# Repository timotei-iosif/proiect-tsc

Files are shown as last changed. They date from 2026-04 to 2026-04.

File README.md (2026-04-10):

# InkTime

In acest proiect a trebuit implementata o schema electrica data de catre echipa
de TSC in Fusion

## Diagrama bloc

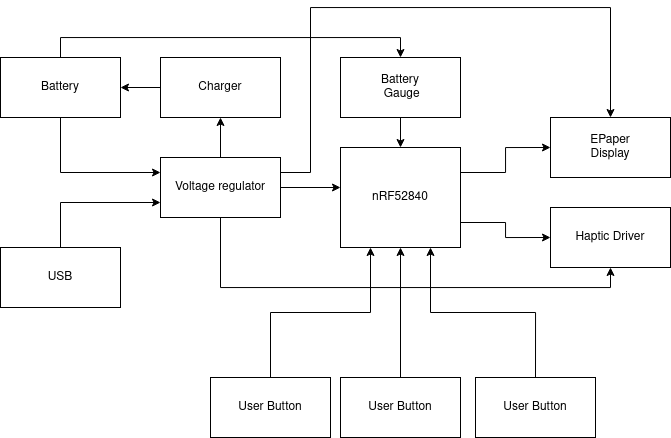
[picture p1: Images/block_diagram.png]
Diagrama block Diagrama bloc


## BOM

|Quantity|Value |Manufacturer Part Number|Link JLCPARTS |
|---|---|---|---|
|1 |2450AT18B100E |2450AT18B100E |https://jlcpcb.com/partdetail/JohansonDielectrics-2450AT18B100E/C2917717 |
|16 |1uF |GRM155R70J105KA12D |https://jlcpcb.com/partdetail/MurataElectronics-GRM155R70J105KA12D/C88945|
|3 |10uF |CC0402MRX7R6BB106 |https://jlcpcb.com/partdetail/YAGEO-CC0402MRX7R6BB106/C3202927 |
|10 |0.1uF |CL03A104KP3NNNC |https://jlcpcb.com/partdetail/50070-CL03A104KP3NNNC/C49062 |
|2 |22uF |CL05A226MQ5QUNC |https://jlcpcb.com/partdetail/YAGEO-CC0402MRX7R6BB106/C3202927 |
|5 |4.7uF |GRM155R61E475ME15D |https://jlcpcb.com/partdetail/3058877-GRM155R61E475ME15D/C2858031 |
|1 |4.7uF/25V |GRM155R61E475ME15D |https://jlcpcb.com/partdetail/3058877-GRM155R61E475ME15D/C2858031 |
|1 |47nF |GRM155R71E473KA88D |https://jlcpcb.com/partdetail/MurataElectronics-GRM155R71E473KA88D/C77017|
|3 |NC | | |
|4 |12pF |GRM0335C1E120JA01D |https://jlcpcb.com/partdetail/172753-GRM0335C1E120JA01D/C161372 |
|1 |100pF |GRM0335C1E101JA01D |https://jlcpcb.com/partdetail/MurataElectronics-GRM0335C1E101JA01D/C76917|
|2 |1pF |GRM0335C1E1R0BA01D |https://jlcpcb.com/partdetail/MurataElectronics-GRM0335C1E1R0BA01D/C88903|
|1 |820pF/NC |GRM0335C1E1R0BA01D |https://jlcpcb.com/partdetail/MurataElectronics-GRM0335C1E1R0BA01D/C88903|
|1 |USBLC6-2SC6Y |USBLC6-2SC6Y |https://jlcpcb.com/partdetail/STMicroelectronics-USBLC62SC6Y/C2969755 |
|3 |MBR0530 |MBR0530 |https://jlcpcb.com/partdetail/78464-MBR0530/C77336 |
|1 |BQ25180YBGR |BQ25180YBGR |https://jlcpcb.com/partdetail/TexasInstruments-BQ25180YBGR/C3682423 |
|1 |RT6160AWSC |RT6160AWSC |https://jlcpcb.com/partdetail/RichtekTech-RT6160AWSC/C7065276 |
|1 |BMA423 |BMA423 |https://jlcpcb.com/partdetail/BoschSensortec-BMA423/C189517 |
|1 |DRV2605YZFR |DRV2605YZFR |https://jlcpcb.com/partdetail/TexasInstruments-DRV2605YZFR/C81079 |
|1 |503480-2400 |503480-2400 |https://jlcpcb.com/partdetail/MOLEX-5034802400/C122434 |
|1 |KH-TYPE-C-16P_KH-TYPE-C-16P |KH-TYPE-C-16P |https://jlcpcb.com/partdetail/Shenzhen_KinghelmElec-KH_TYPE_C16P/C709357 |
|1 |TC2030-IDC |TC2030-IDC |- |
|1 |FTC252012SR47MBCA |FTC252012SR47MBCA |https://jlcpcb.com/partdetail/6763488-FTC252012SR47MBCA/C5832368 |
|1 |68uH |CMI322513J680M |https://jlcpcb.com/partdetail/61593-CMI322513J680M/C60541 |
|1 |10uH |SDFL2012S100KTF |https://jlcpcb.com/partdetail/Sunlord-SDFL2012S100KTF/C1046 |
|1 |15uH |CMI201209J150KT |https://jlcpcb.com/partdetail/76759-CMI201209J150KT/C75634 |
|1 |3.9nH |CMI201209U3R9KT |https://jlcpcb.com/partdetail/70603-CMI201209U3R9KT/C69486 |
|1 |SI1308EDL-T1-GE3 |SI1308EDL-T1-GE3 |https://jlcpcb.com/partdetail/VishayIntertech-SI1308EDL_T1GE3/C469327 |
|1 |20V/4.2A/52mOhm/1.4W |AO3401A |https://jlcpcb.com/partdetail/Alpha_OmegaSemicon-AO3401A/C15127 |
|6 |10k |CR0201FH1002G |https://jlcpcb.com/partdetail/LIZElec-CR0201FH1002G/C100126 |
|3 |0 |RC0201FR-070RL |https://jlcpcb.com/partdetail/YAGEO-RC0201FR070RL/C106227 |
|2 |3k3 |RM02JTN332 |https://jlcpcb.com/partdetail/TA_ITech-RM02JTN332/C162771 |
|2 |5k1 |CR0201FH5101G |https://jlcpcb.com/partdetail/LIZElec-CR0201FH5101G/C100142 |
|1 |0.47 |RL73V1HR47FTDF |https://jlcpcb.com/partdetail/TEConnectivity-RL73V1HR47FTDF/C2139167 |
|1 |2.2 |RTT012R2JTH |https://jlcpcb.com/partdetail/RALEC-RTT012R2JTH/C102714 |
|1 |MAX17048G+T10 |MAX17048G+T10 |https://jlcpcb.com/partdetail/2777647-MAX17048GT10/C2682616 |
|1 |NRF52840_QF |NRF52840_QF |https://jlcpcb.com/partdetail/NordicSemicon-NRF52840_QFAA_FR/C3606918 |
|1 |32Mhz |830108212909 |https://jlcpcb.com/partdetail/357112-X201632MMB4SI/C383840 |
|1 |32.768kHz |X201632MMB4SI |https://jlcpcb.com/partdetail/SeikoEpson-Q13FC13500004/C32346 |

## Module folosite

### 1. Mcu

Controlerul principal al placii este un nRF52840, bazat pe un nucleu ARM
Cortex-M4F la 64 MHz.

* Clocking: Sistemul utilizeaza doua ceasuri. Un oscilator extern de 32 MHz
  pentru core, periferice si RF, si oscilator de 32.768 kHz este utilizat
  pentru RTC
* Interfata RF: 2450AT18B100E - banda de 2.4 GHz, integrata cu o retea de
  adaptare a impedantei formata din componente pasive
* Interfete de date:
    * **I2C:** Magistrala pentru senzor IMU, fuel gauge, charger, driver haptic
    * **SPI:** Pentru display-ul E-Paper.
    * **USB:** Liniile D+ ai D- sunt rutate direct la pinii nativi ai nRF52840

### 2. Module

* **Incarcare:** Implementat cu un BQ25180. Preia tensiunea de 5V de pe
  magistrala VBUS (USB) si gestioneaza ciclul de incarcare al celulei LiPo.
  Configurabil folosind I2C + PMIC\_INT
* **Regulatoare:** Buck-boost - Richtek RT6160. Rolul sau este sa asigure o
  tensiune stabila de 3.3V
* **Monitorizare:** MAX17048 citeste starea de incarcare a bateriei. Ofera
  alerte hardware la praguri predefinite de descarcare.
* **Afisaj E-Paper**
* **Sistem Haptic:** - DRV2605. Este comandat prin I2C si activat via pinul
  HAPTIC\_EN`.
* **Inertial Measurement Unit (IMU):** BMA421. Liniile de intrerupere
  (`IMU\_INT1`, `IMU\_INT2`) sunt folosite pentru algoritmul de wake-on-tilt.
* **3 Butoane fizice**

## 3. Calcule Estimative de Consum (Power Budget)

1.  **Standby**: ~10 - 20 uA
2.  **Radio activ (BLE TX/RX): ~5 - 15 mA**
3.  **Actualizare Display (Refresh E-Paper):** ~5 - 15 mA (timp de 1-3 secunde)
4.  **Feedback Haptic:** 50 - 100+ mA pentru perioade scurte

## Pini de nRF52840

Conform manualului de referinta a nRF52840 pinii pentru protocoale digitale (cu
exceptia USB si SWD) pot fi rutati la orice pin fizic ai microcontrollerului.
Alegerea pinilor pentru aceste protocoale a fost facuta pentru a facilita
rutarea de semnale.

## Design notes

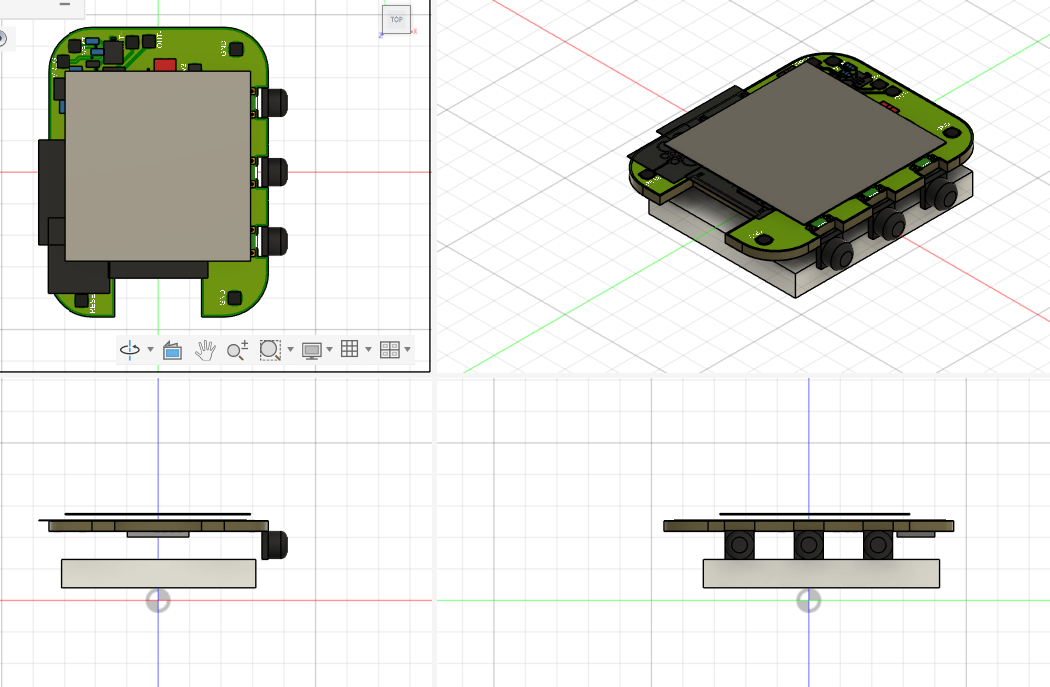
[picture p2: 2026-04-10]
Images/3D.png

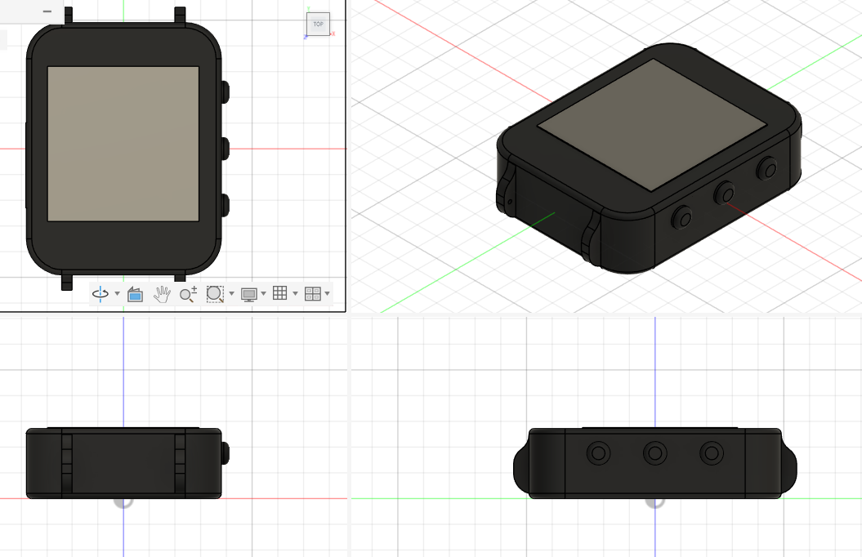
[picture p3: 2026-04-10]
Images/3D_2.png

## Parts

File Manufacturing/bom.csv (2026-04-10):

Reference Designators | Quantity | Description | Package | Value | Manufacturer Part Number | Link JLCPARTS
 | 1 | PCB Board | Board
ANT1 | 1 | Antennas 2.45GHz ANTENNA | 2450AT18B100E_ANTC3216X140N | 2450AT18B100E | 2450AT18B100E | https://jlcpcb.com/partdetail/JohansonDielectrics-2450AT18B100E/C2917717
C1, C3, C11, C14, C15, C16, C19, C20, C22, C23, C24, C25, C26, C27, C28, C31 | 16 | Generic chip capacitor | NORDIC_NRF_3_RESC0402_N | 1uF | GRM155R70J105KA12D | https://jlcpcb.com/partdetail/MurataElectronics-GRM155R70J105KA12D/C88945
C2, C4, C18 | 3 | Generic chip capacitor | NORDIC_NRF_3_RESC0402_N | 10uF | CC0402MRX7R6BB106 | https://jlcpcb.com/partdetail/YAGEO-CC0402MRX7R6BB106/C3202927
C5, C8, C9, C10, C13, C21, C30, C34, C43, C44 | 10 | Generic chip capacitor | NORDIC_NRF_3_RESC0201_N | 0.1uF | CL03A104KP3NNNC | https://jlcpcb.com/partdetail/50070-CL03A104KP3NNNC/C49062
C6, C7 | 2 | Generic chip capacitor | NORDIC_NRF_3_RESC0402_N | 22uF | CL05A226MQ5QUNC | https://jlcpcb.com/partdetail/YAGEO-CC0402MRX7R6BB106/C3202927
C12, C29, C45, C46, C47 | 5 | Generic chip capacitor | NORDIC_NRF_3_RESC0402_N | 4.7uF | GRM155R61E475ME15D | https://jlcpcb.com/partdetail/3058877-GRM155R61E475ME15D/C2858031
C17 | 1 | Generic chip capacitor | NORDIC_NRF_3_RESC0402_N | 4.7uF/25V | GRM155R61E475ME15D | https://jlcpcb.com/partdetail/3058877-GRM155R61E475ME15D/C2858031
C32 | 1 | Generic chip capacitor | NORDIC_NRF_3_RESC0201_N | 47nF | GRM155R71E473KA88D | https://jlcpcb.com/partdetail/MurataElectronics-GRM155R71E473KA88D/C77017
C33, C38, C41 | 3 | Generic chip capacitor | NORDIC_NRF_3_RESC0201_N | NC
C35, C36, C48, C49 | 4 | Generic chip capacitor | NORDIC_NRF_3_RESC0201_N | 12pF | GRM0335C1E120JA01D | https://jlcpcb.com/partdetail/172753-GRM0335C1E120JA01D/C161372
C37 | 1 | Generic chip capacitor | NORDIC_NRF_3_RESC0201_N | 100pF | GRM0335C1E101JA01D | https://jlcpcb.com/partdetail/MurataElectronics-GRM0335C1E101JA01D/C76917
C39, C40 | 2 | Generic chip capacitor | NORDIC_NRF_3_RESC0201_N | 1pF | GRM0335C1E1R0BA01D | https://jlcpcb.com/partdetail/MurataElectronics-GRM0335C1E1R0BA01D/C88903
C42 | 1 | Generic chip capacitor | NORDIC_NRF_3_RESC0201_N | 820pF/NC | GRM0335C1E1R0BA01D | https://jlcpcb.com/partdetail/MurataElectronics-GRM0335C1E1R0BA01D/C88903
D1 | 1 | Low Cap. ESD Protection Auto SOT-23-6 STMicroelectronics USBLC6-2SC6Y, Dual Uni-Directional TVS Diode Array, 6-Pin SOT-23 | ESP32_C6_LIBRARY_3_SOT95P280X145-6N | USBLC6-2SC6Y | USBLC6-2SC6Y | https://jlcpcb.com/partdetail/STMicroelectronics-USBLC62SC6Y/C2969755
D2, D3, D4 | 3 | ON SEMICONDUCTOR - MBR0530 - DIODE, SCHOTTKY, 0.5A, 30V, SOD-123 | ESP32_C6_LIBRARY_5_SOD3716X135N | MBR0530 | MBR0530 | https://jlcpcb.com/partdetail/78464-MBR0530/C77336
IC1 | 1 | Charger IC Lithium Ion/Polymer, Lithium Iron Phosphate 8-DSBGA (1.6x1.1) | BQ25180YBGR_BGA8C40P2X4_100X155X50 | BQ25180YBGR | BQ25180YBGR | https://jlcpcb.com/partdetail/TexasInstruments-BQ25180YBGR/C3682423
IC2 | 1 | Buck-Boost Regulator Positive Output Step-Up/Step-Down I2C DC-DC Controller IC 15-WL-CSP (BSC) (1.4x2.3) | RT6160AWSC_BGA15C40P3X5_140X230X60 | RT6160AWSC | RT6160AWSC | https://jlcpcb.com/partdetail/RichtekTech-RT6160AWSC/C7065276
IC3 | 1 | Accelerometers Triaxial low-g 12bit Acceleration Sensor | BMA423_BMA423 | BMA423 | BMA423 | https://jlcpcb.com/partdetail/BoschSensortec-BMA423/C189517
IC4 | 1 | Haptic Driver for ERM/LRA with Built-In Library and Smart Loop Architecture | DRV2605YZFR_BGA9C50P3X3_144X144X62 | DRV2605YZFR | DRV2605YZFR | https://jlcpcb.com/partdetail/TexasInstruments-DRV2605YZFR/C81079
J1 | 1 | FFC & FPC Connectors 0.5mm FPC RA SMT Dual Contact 24Ckt | 503480-2400_5034802400 | 503480-2400 | 503480-2400 | https://jlcpcb.com/partdetail/MOLEX-5034802400/C122434
J2 | 1 | Check availability | KH-TYPE-C-16P_KINGHELM_KH-TYPE-C-16P | KH-TYPE-C-16P_KH-TYPE-C-16P | KH-TYPE-C-16P | https://jlcpcb.com/partdetail/Shenzhen_KinghelmElec-KH_TYPE_C16P/C709357
J5 | 1 | CABLE ADAPTER 6 POS | TC2030-IDC_TC2030IDC | TC2030-IDC | TC2030-IDC | -
L1 | 1 | SMD / SMT Inductors (Coils), L=0.47?H, L x W x T : | MLP2016SR47MT0S1_INDC2016X100N | FTC252012SR47MBCA | FTC252012SR47MBCA | https://jlcpcb.com/partdetail/6763488-FTC252012SR47MBCA/C5832368
L2 | 1 | Generic chip inductor | NORDIC_NRF_2_RESC0402_L | 68uH | CMI322513J680M | https://jlcpcb.com/partdetail/61593-CMI322513J680M/C60541
L3 | 1 | SMD / SMT Inductors (Coils), L=0.47?H, L x W x T : | MLP2016SR47MT0S1_INDC2016X100N | 10uH | SDFL2012S100KTF | https://jlcpcb.com/partdetail/Sunlord-SDFL2012S100KTF/C1046
L4 | 1 | SMD / SMT Inductors (Coils), L=0.47?H, L x W x T : | MLP2016SR47MT0S1_INDC2016X100N | 15uH | CMI201209J150KT | https://jlcpcb.com/partdetail/76759-CMI201209J150KT/C75634
L5 | 1 | SMD / SMT Inductors (Coils), L=0.47?H, L x W x T : | MLP2016SR47MT0S1_INDC2016X100N | 3.9nH | CMI201209U3R9KT | https://jlcpcb.com/partdetail/70603-CMI201209U3R9KT/C69486
Q1 | 1 | MOSFET N-Ch 30V 1.5A TrenchFET SC70 Vishay Si1308EDL-T1-GE3 N-channel MOSFET Transistor, 1.5 A, 30 V, 3-Pin SC-70 | ESP32_C6_LIBRARY_6_SOT65P210X110-3N | SI1308EDL-T1-GE3 | SI1308EDL-T1-GE3 | https://jlcpcb.com/partdetail/VishayIntertech-SI1308EDL_T1GE3/C469327
Q2 | 1 | P-channel MOSFETs | ESP32_C6_LIBRARY_4_ESP32_C6_LIBRARY_4_ESP32_C6_LIBRARY_4_ESP32_C6_LIBRARY_4_ESP32_WROVER_SPARKFUN-DISCRETESEMI_SOT23-3 | 20V/4.2A/52mΩ/1.4W | AO3401A | https://jlcpcb.com/partdetail/Alpha_OmegaSemicon-AO3401A/C15127
R1, R9, R10, R11, R12, R15 | 6 | 7.68k 0201 Thin Film Surface Mount Fixed Resistor +/-0.5% 0.031W CPF0201D7K68C1 | CPF0201D7K68C1_0201 | 10k | CR0201FH1002G | https://jlcpcb.com/partdetail/LIZElec-CR0201FH1002G/C100126
R2, R3, R6 | 3 | 7.68k 0201 Thin Film Surface Mount Fixed Resistor +/-0.5% 0.031W CPF0201D7K68C1 | CPF0201D7K68C1_0201 | 0 | RC0201FR-070RL | https://jlcpcb.com/partdetail/YAGEO-RC0201FR070RL/C106227
R4, R5 | 2 | 7.68k 0201 Thin Film Surface Mount Fixed Resistor +/-0.5% 0.031W CPF0201D7K68C1 | CPF0201D7K68C1_0201 | 3k3 | RM02JTN332 | https://jlcpcb.com/partdetail/TA_ITech-RM02JTN332/C162771
R7, R8 | 2 | 7.68k 0201 Thin Film Surface Mount Fixed Resistor +/-0.5% 0.031W CPF0201D7K68C1 | CPF0201D7K68C1_0201 | 5k1 | CR0201FH5101G | https://jlcpcb.com/partdetail/LIZElec-CR0201FH5101G/C100142
R13 | 1 | 7.68k 0201 Thin Film Surface Mount Fixed Resistor +/-0.5% 0.031W CPF0201D7K68C1 | CPF0201D7K68C1_0201 | 0.47 | RL73V1HR47FTDF | https://jlcpcb.com/partdetail/TEConnectivity-RL73V1HR47FTDF/C2139167
R14 | 1 | 7.68k 0201 Thin Film Surface Mount Fixed Resistor +/-0.5% 0.031W CPF0201D7K68C1 | CPF0201D7K68C1_0201 | 2.2 | RTT012R2JTH | https://jlcpcb.com/partdetail/RALEC-RTT012R2JTH/C102714
SJ2 | 1 | SMD solder JUMPER | ESP32_C6_LIBRARY_7_JUMPER_SJ | -
SW_DN, SW_ENT, SW_UP | 3 |  | 2025-10-22_07-23-44_LIBRARY_SW_EVP-AKE31A_PAN | 2025-10-22_07-23-44_LIBRARY_EVP-AKE31ASW_EVP-AKE31A_PAN
TP_3.3V, TP_3V3, TP_GND, TP_OUT-, TP_OUT+, TP_RESET, TP_SWCLK, TP_SWDIO, TP_SWO, TP_VBAT, TP_VBAT_GND, TP_VREG | 12 | Test pad | HECTOR_WATCH_1_TP20R | HECTOR_WATCH_1_TPTP20R
U1 | 1 | Check availability | ESP32_C6_LIBRARY_SON50P200X200X80-9N | MAX17048G+T10 | MAX17048G+T10 | https://jlcpcb.com/partdetail/2777647-MAX17048GT10/C2682616
U2 | 1 | nRF52840 | NORDIC_NRF_4_AQFN50P700X700X85_HS-74N | NRF52840_QF | NRF52840_QF | https://jlcpcb.com/partdetail/NordicSemicon-NRF52840_QFAA_FR/C3606918
X1 | 1 |  | NORDIC_NRF_BT-XTAL_2016_N | 32Mhz | 830108212909 | https://jlcpcb.com/partdetail/357112-X201632MMB4SI/C383840
X2 | 1 |  | NORDIC_NRF_1_XTAL_3215_N | 32.768kHz | X201632MMB4SI | https://jlcpcb.com/partdetail/SeikoEpson-Q13FC13500004/C32346

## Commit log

2026-04-10 Added hardware. No 3D
    [bom.csv, tsc.brd, tsc.sch]
2026-04-10 Finished BOM
    [bom.csv]
